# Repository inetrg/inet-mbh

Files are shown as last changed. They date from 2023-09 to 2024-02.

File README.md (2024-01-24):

# inet-mbh
The Modular Board Holder design for the inet-nm from the INET working group.

## Purpose
The goal of this (aside from learning) is to create a stackable, expandable case
to hold the many different types of embedded development kits we use.
We would like to have an easy way to connect and disconnect these development
kits to a server via USB hubs (similar to quick swap HDDs or drives).

## Glossary
- `bc_s` (Board Clip - Single) - A pcb board holder clip fitting a single position.
- `bc_d` (Board Clip - Dual) - A pcb board holder clip fitting a two positions.
- `bh` (Board Holder) - The flat slot that the board and usb will clip into.
- `mbh` (Modular Board Holder) - The overall project.
- `mc` (Modular Container) - The large box that interconnects.
- `src` (Sliding Ratchet Clip) - Is a clip used to fasten the SRH to a specific position acting like the other size  of the zip tie.
- `srh` (Sliding Ratchet Holder) - Holds the center of a USB cable in a position, it has ridges similar to a zip tie that can be used to adjust an axis.
- `umh` (USB Modular Holder)

- ~~`cbc` (Corner Board Clip) - A clip that connects to bh that holds the corner of boards~~
- ~~`sbc` (Side Board Clip) - A clip that connects to bh that holds the side of boards~~
- ~~`ube` (USB Bunny Ears) - The spring mechanism to push the usb cable up~~
- ~~`uc` (USB Cap) - The usb specific cap that clips in over top of the usb casing~~

## Requirements

Software version used to model this:
```
freecad-0.21.1
```

Slicer for the 3D printing:
```
prusaslicer-2.7.1
```

Panel Mount USB connector
```
Manufacturer Product Number: 4055
Manufacturer: Adafruit Industries LLC
url: https://www.digikey.de/en/products/detail/adafruit-industries-llc/4055/10107220
```

USB Hub (has power control with [uhubctl](https://github.com/mvp/uhubctl))
```
Manufacturer Product Number: HU9003V1EBL
Manufacturer: Amazon Basics
url: https://www.amazon.de/-/en/Amazon-Basics-Ports-Power-Adapter/dp/B076YKYHCB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
```

## Flashy Pictures

20 connected with 5 `mc`s offset
mbh-full-front

Different form factor boards
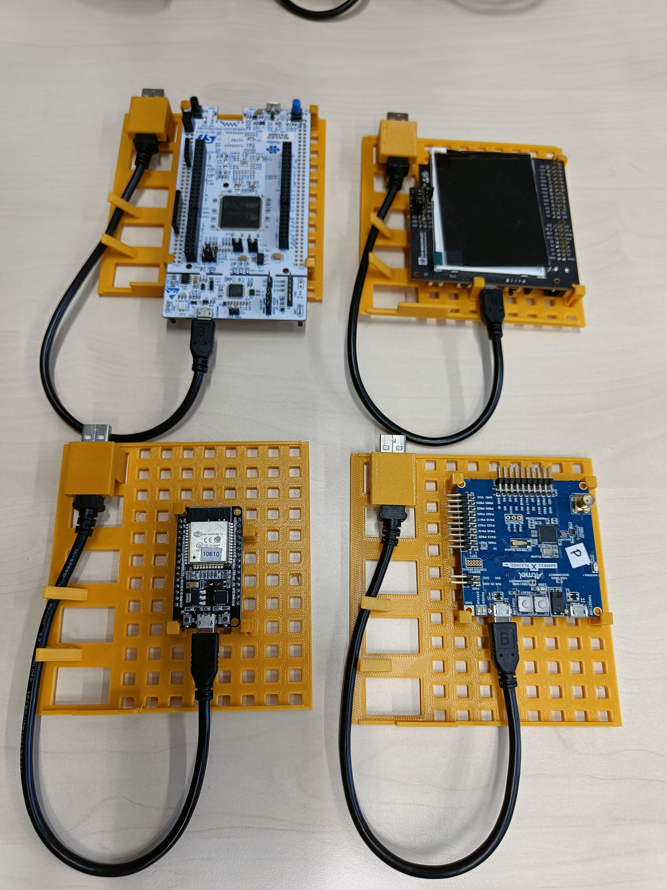
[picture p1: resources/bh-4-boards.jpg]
bh-4-boards


Empty `mc`
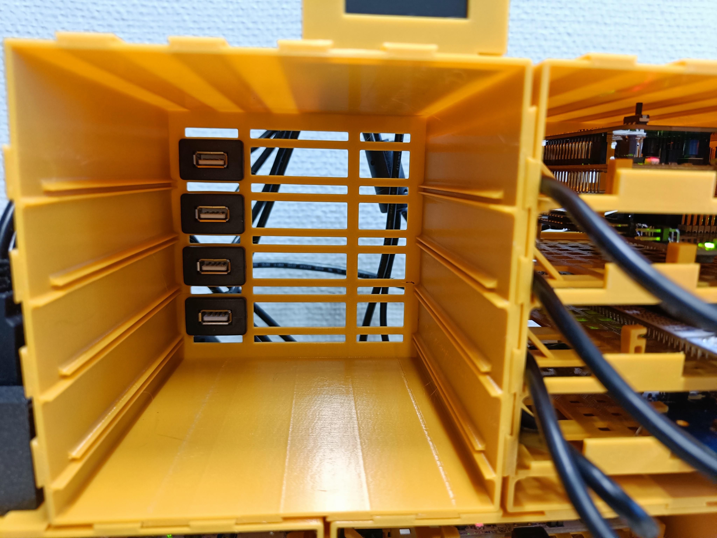
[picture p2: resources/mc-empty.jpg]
mc-empty


All the different pieces:
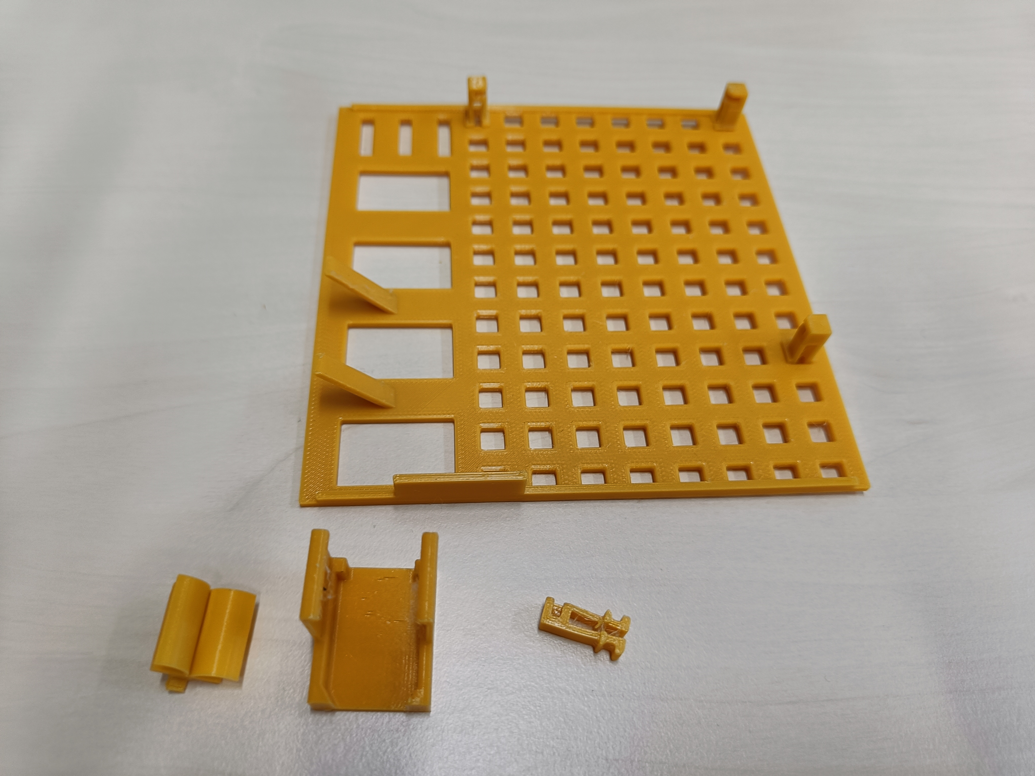
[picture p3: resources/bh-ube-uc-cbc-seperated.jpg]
bh-ube-uc-cbc-seperated


## Roadmap

- Create a "service" where some basic parameters are entered and out pops an
stl for those given parameters.
- Automate releases to provide all the stl files in a reproducible way.
- Add a place to label the `mc` for location
- Add an open PCB
    - 4x USB hub
    - Bussed power
    - Power control
    - Indicator LEDs
    - Bussed communications

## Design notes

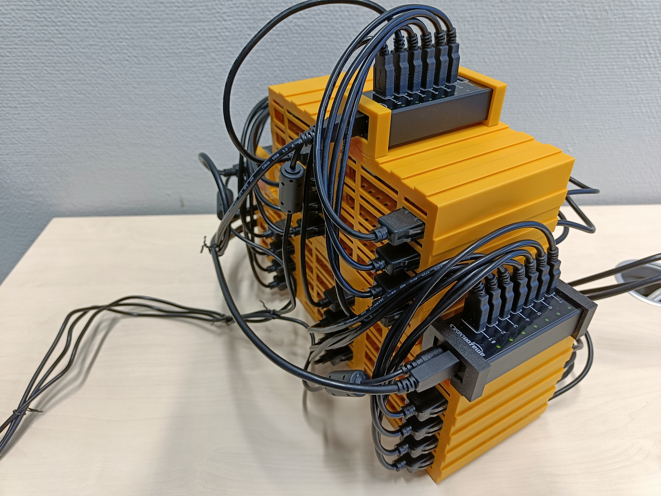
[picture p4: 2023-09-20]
resources/mbh-full-back-top.jpg

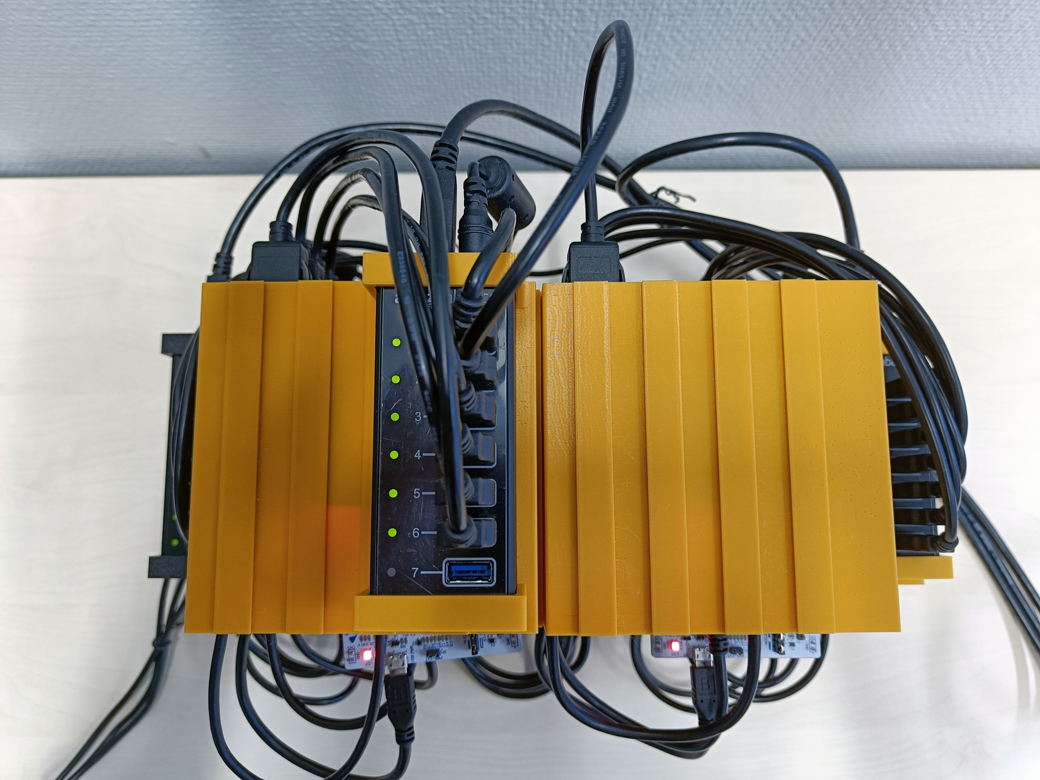
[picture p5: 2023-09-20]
resources/mbh-full-top.jpg

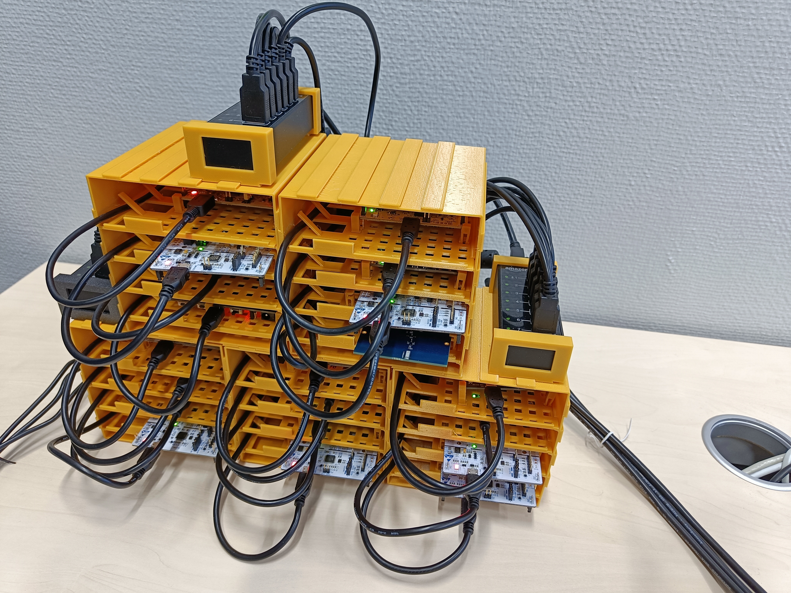
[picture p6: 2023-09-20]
resources/mbh-full-top-right.jpg

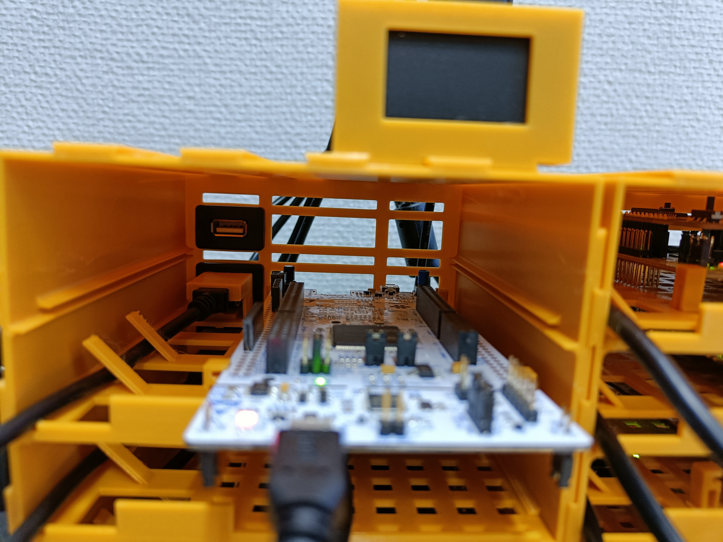
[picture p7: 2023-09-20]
resources/mc-inside-top-empty.jpg

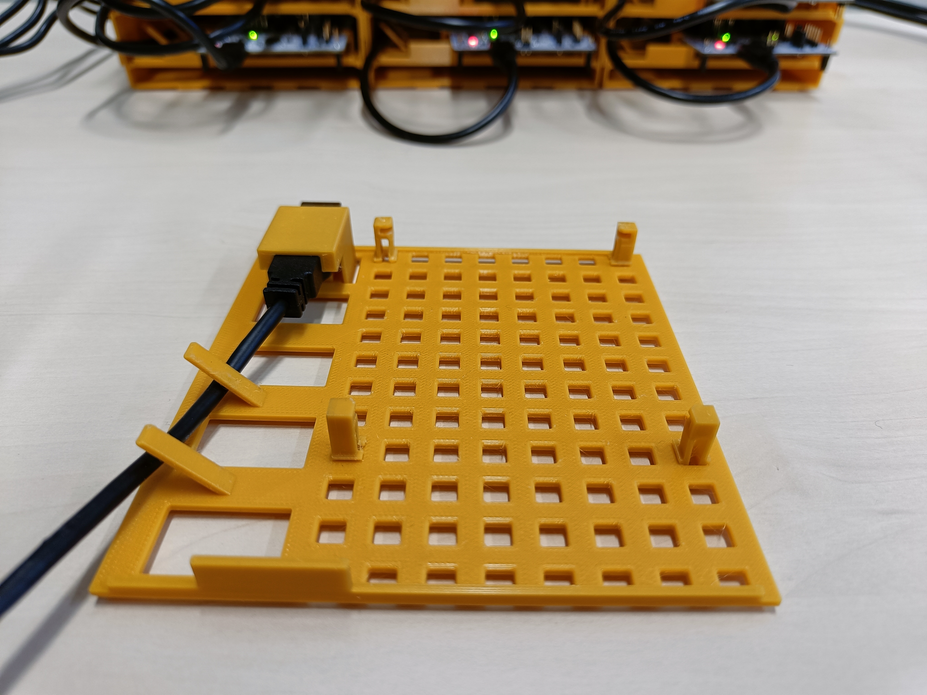
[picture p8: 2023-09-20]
resources/bh-no-board.jpg

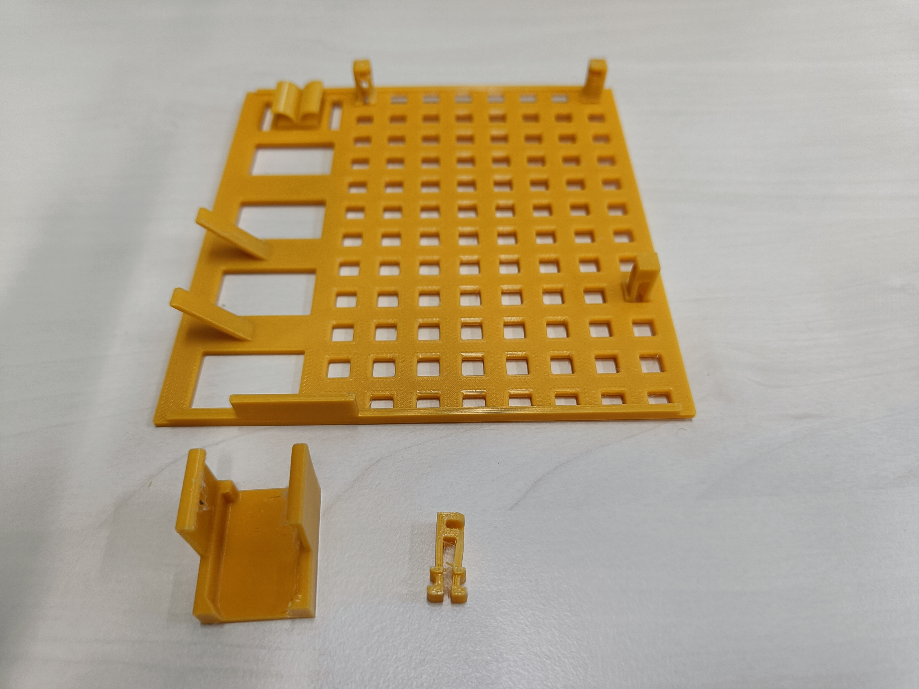
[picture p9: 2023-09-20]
resources/bh-no-uc-cbc.jpg

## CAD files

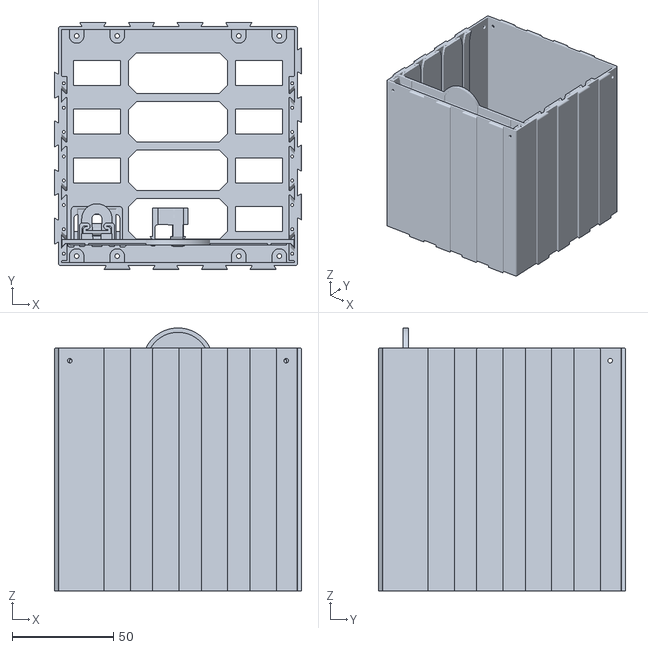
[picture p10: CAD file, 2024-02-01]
resources/inet-mbh-v1_0_1.stl
122.0 x 122.0 x 129.8

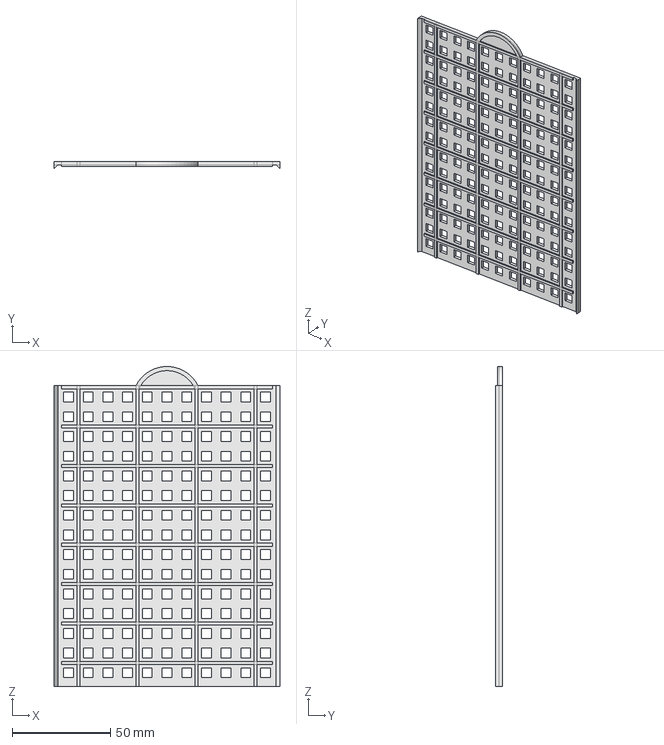
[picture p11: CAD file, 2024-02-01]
src/mbh_long.FCStd
114.6 x 3.60 x 162.6 mm

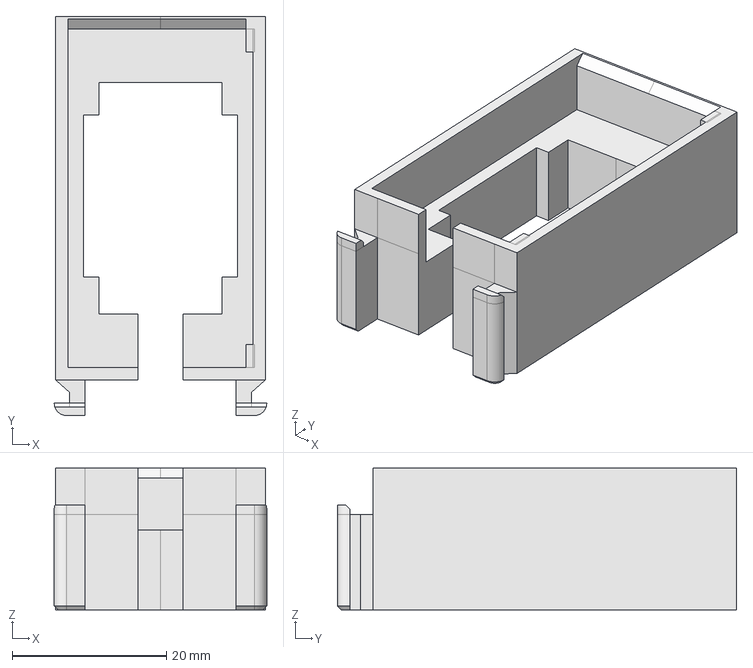
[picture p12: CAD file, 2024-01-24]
src/hub_holder.FCStd
27.6 x 51.8 x 18.4 mm

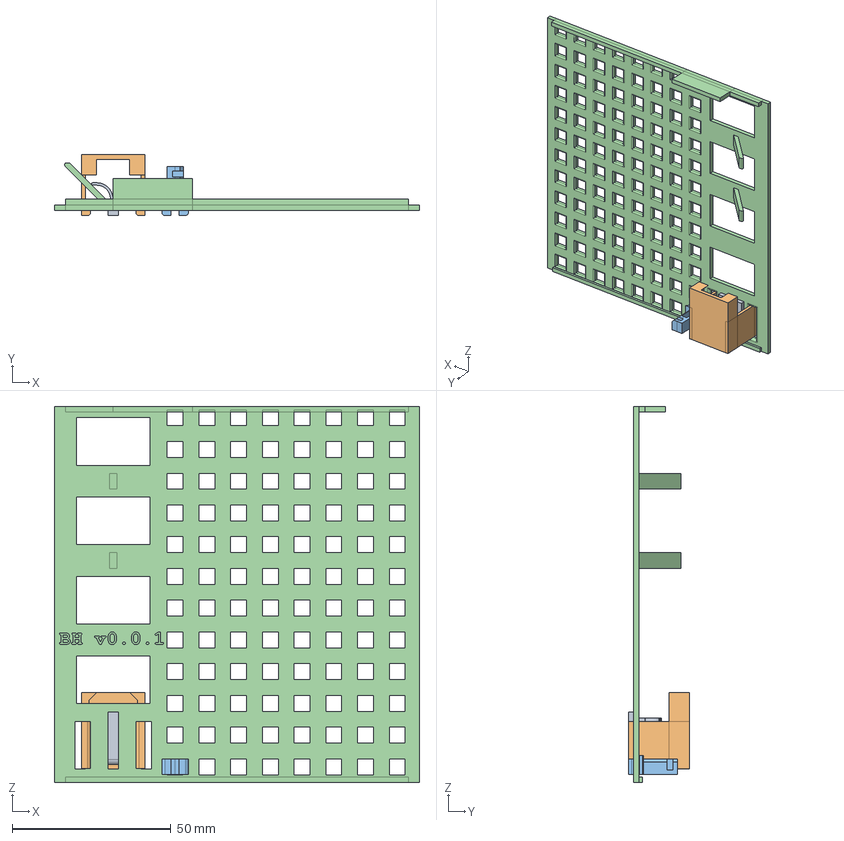
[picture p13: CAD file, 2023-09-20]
src/mbh.FCStd
115.0 x 19.3 x 118.6 mm
usb_bunny_ears
uc_template
cbc
Cut_inet_bh_ver

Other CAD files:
resources/inet-mbh-v1_0_0.stl

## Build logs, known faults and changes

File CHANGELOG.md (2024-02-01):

Changelog
=========

Latest
======

Version 1.0.1
-------------

Small change to make the board holders (bh) thinner as they interfered with
some buttons on the large nucleo boards. They are a bit more flimsy but enough
for the purpose and allows more overall height.

- Both the bh and bh_long are the only things affected.
- The stability_z size decreased from 1.6mm to 0.8mm

Version 1.0.0
-------------

The internal board holders are not compatible with previous modular cases due
to the change of position of the USB socket position. However, previous modular
cases fit the same grid and can be used with the current design.

- Replaced vendor specific USB holder design with generic USB holder
- Added new PCB board holder clips allowing corners to fit a 2.5mm grid instead
of every 10mm.
- Added triangle edges for the board holder card to improve warping of the case
when weight is applied
- Added more support beams through the board holder card
- Added better guide rails to the modular case
- Added holes for light pipes to the module case
- Added 2.5mm holes (20 mm x 108.6mm) with nut support for USB hub PCB mounting
- Added 2.5mm holes to the front edges of the module case to prevent slipping
- Standardize the board holder grid
- Changed the back of the board holder to make it stronger and save material

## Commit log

2023-09-20 src(mbh): Initial commit of freecad file
    [mbh.FCStd]
2024-01-24 feat: Release v1.0.0
    [hub_holder.FCStd, inet-mbh-v1_0_0.stl, mbh_long.FCStd]
2024-02-01 fix: release with thinner supports
    [inet-mbh-v1_0_1.stl, mbh_long.FCStd]
